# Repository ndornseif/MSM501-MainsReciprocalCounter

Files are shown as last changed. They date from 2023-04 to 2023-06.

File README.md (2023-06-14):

# MSM501-Mains Reciprocal Counter
Measures the frequency of mains power.  

## Overview
This device was built as an exercise in digital electronics.  
It uses a reciprocal frequency counter approach to measure the frequency of the mains voltage supplying it.   
Using two SN74LV8154N 32-bit counters, it counts pulses of the mains signal and the reference clock.  
The start and end of the measurement are synchronized to the input signal, using a D-Flip-Flop to open the main gate.  
This eliminates the influence of gate time accuracy on the measurement.  
The measurement result is then calculated as follows:  
$f_{measured} = \frac{n_{SignalCounter}}{n_{RefCounter}} \times f_{Ref}$   
The measured value is sent out over serial (J2).  
Find a graph explaining the signal flow [here](Charts/Signalflow.pdf).  

## Board overview
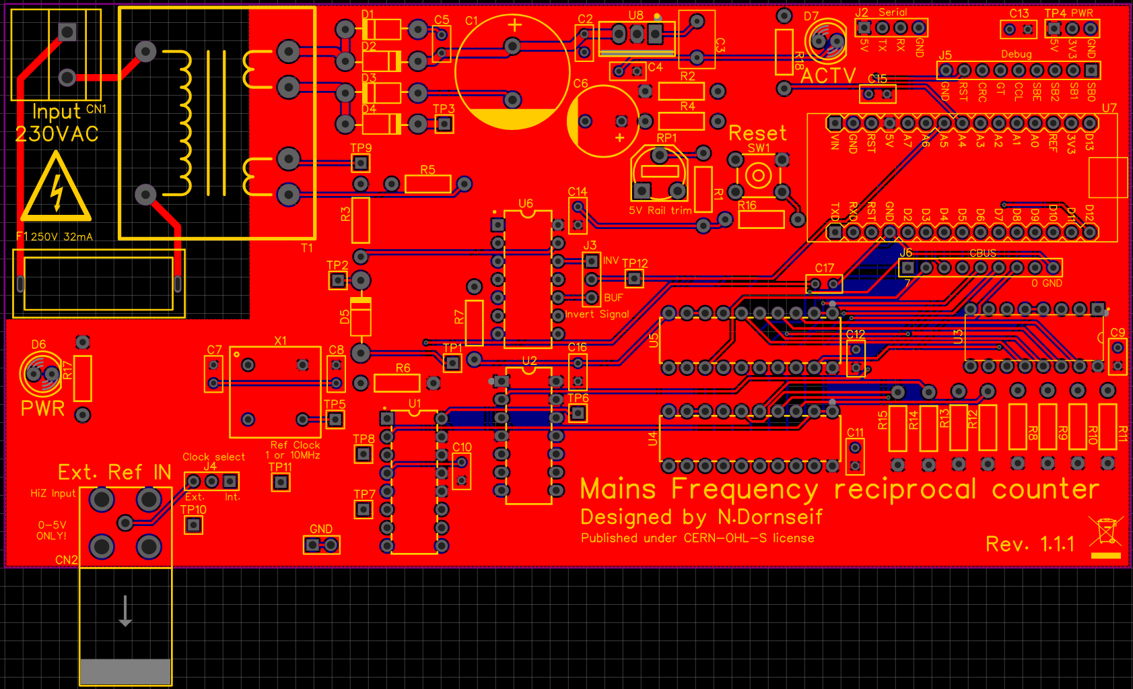
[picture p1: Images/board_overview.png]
Topside of the circuit board
  

## Connectors/Headers
- GND: Ground connection for scope ground clips.  
- TP4: DC voltage rails.
- J2: Serial interface. Connected to D0 and D1 of the Arduino. (5V max.)
- J5: Debug pins. (SBUS0, SBUS1, SBUS2, SBUSE, CounterClear, GateTime, CounterRegClock, Reset)
- J6: CBUS. Used to read out the counter values.
- CN1: Mains input. Fuse with a 5x20mm 32mA glass fuse in F1.
- CN2: External reference input. BNC. 0–5V square wave only. HiZ input.

## Jumpers
- JMP1 (J3): Selects if the measured signal is inverted. This should not affect the measured value. The recommended setting is INV.
- JMP2 (J4): Selects an external or internal reference clock. Check TP11 for the selected signal.

## Test points
- TP1:  Offset voltage to compensate for the clipping diode drop. (~ 500mV DC)
- TP2:  Divided and clipped transformer output voltage. (~ 4V<sub>p</sub> half-wave rectified sine)
- TP3:  Unregulated rectified and smoothed transformer voltage. (> 17V DC)
- TP4:  DC supply rails. (+5V and +3.3V DC)
- TP5:  Reference oscillator signal. (1 MHz or 10 MHz 0–5V square wave)
- TP6:  Gate-Enable signal from Flip-Flop. High if the main gate is open and the measurement is running.
- TP7:  Input to the signal counter.
- TP8:  Input to the reference counter.
- TP9:  Transformer output voltage to measurement circuit. (> 12V AC)
- TP10: External reference clock input.
- TP11: Reference input to the main gate. Should show the same signal as TP10 or TP5 depending on JMP2 (clock select).
- TP12: Signal input to the main gate. (0-5V square wave with the same frequency as the mains)

## Trimmers
- RP1:  Use this pot to adjust the voltage of the 5V rail.  

## Firmware 
Find the firmware for this project in this [repository](https://github.com/ndornseif/MSM501-Firmware).  
You can just upload it using the official Arduino IDE onto the Arduino Nano (U7).  
Remove the Arduino from the board when uploading firmware.  
Measurement results are in uHz and sent out over serial.  
They are sent as ASCII and separated by LF and CR.   
Default parameters: 115200 baud, 8 data, 1 stop, no parity  

## Example data
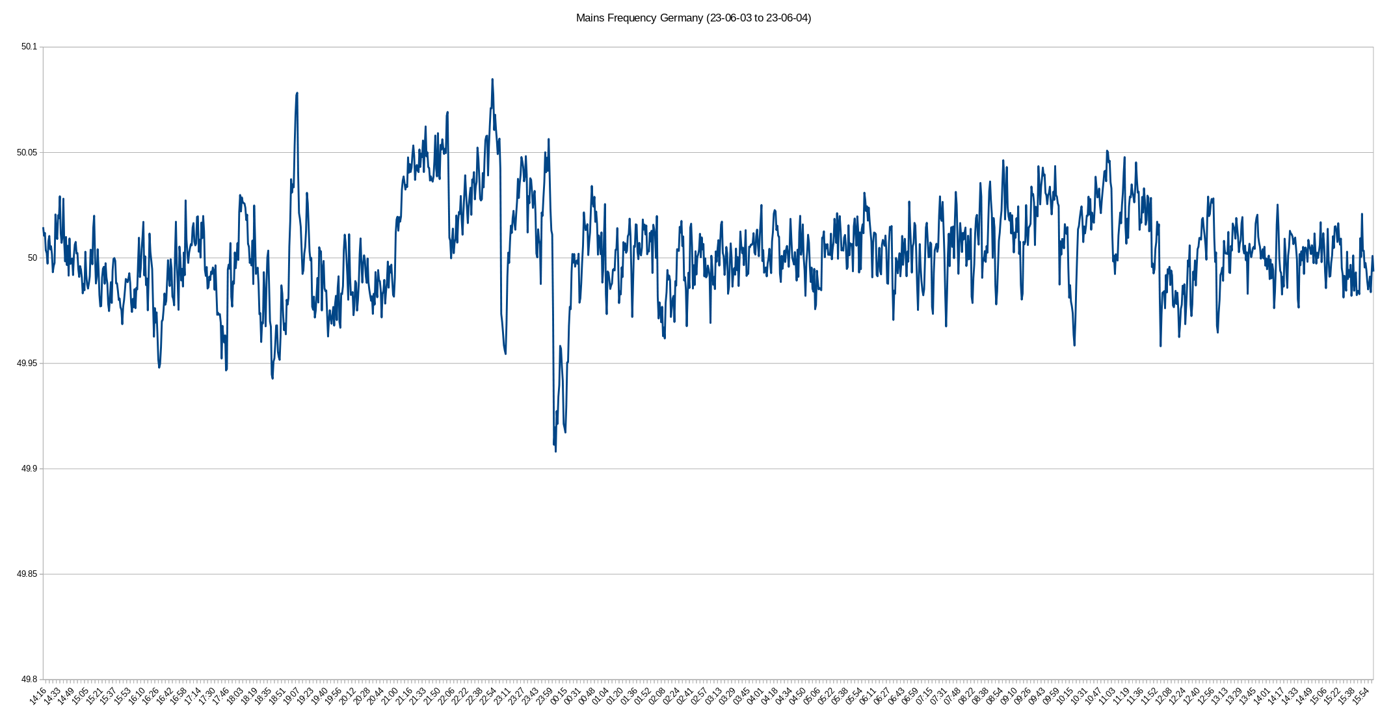
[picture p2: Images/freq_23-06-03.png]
Mains Frequency in Germany


## Considerations
Trying to power the Arduino through its USB header while the device is connected to the mains is not recommended.  
Use J2 (serial) for communication while mains is applied.  

## Other
Published under CERN-OHL-S license.

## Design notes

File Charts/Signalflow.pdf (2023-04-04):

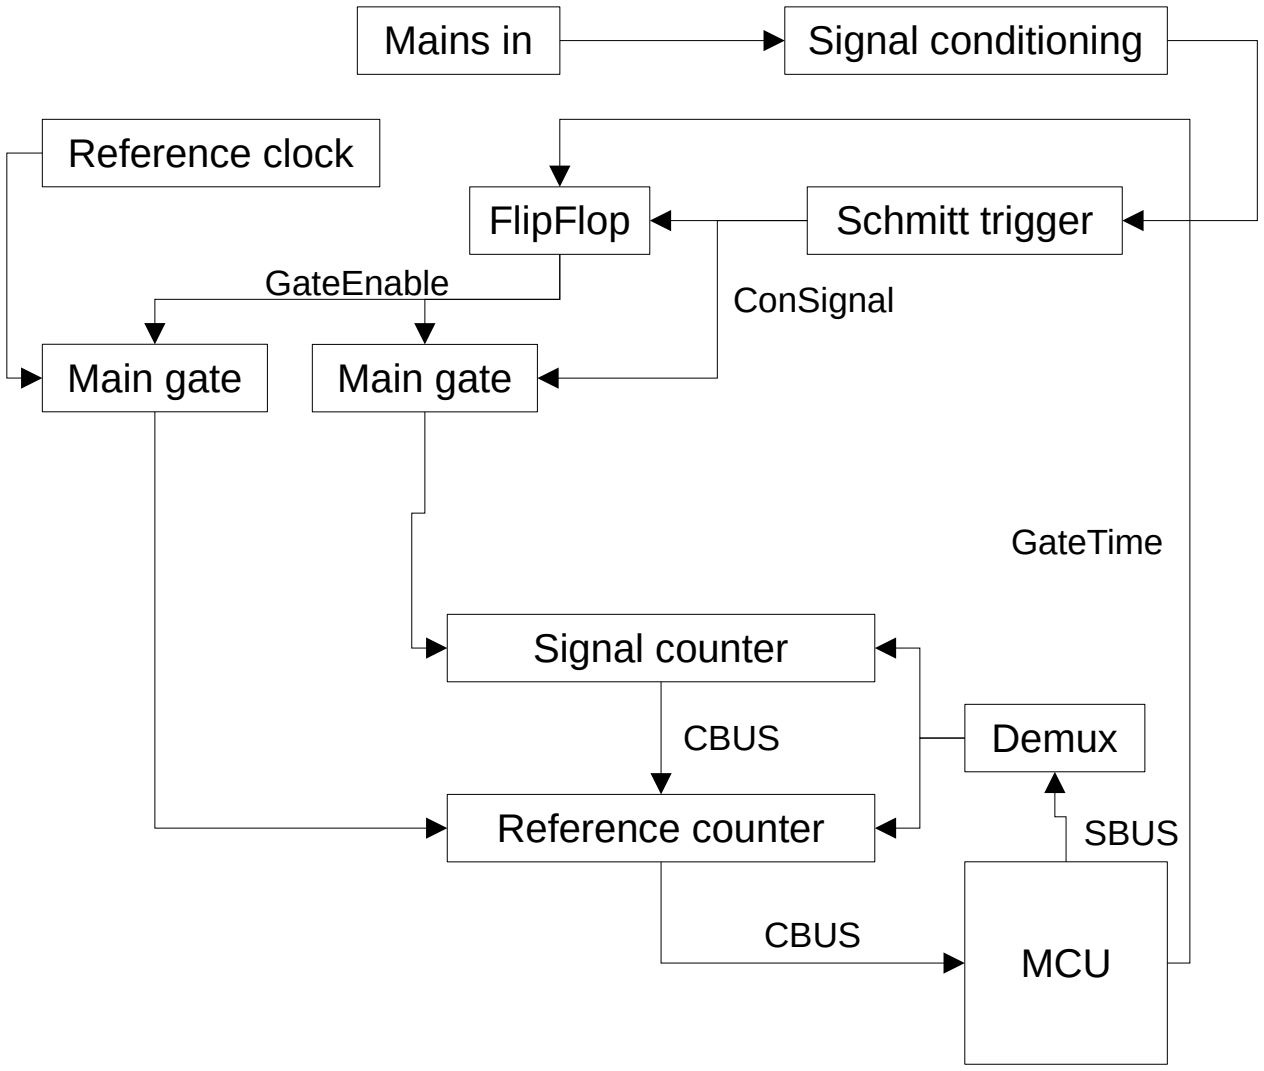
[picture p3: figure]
Reference counter; Signal counter; Demux; MCU; SBUS; Main gate; FlipFlop; Signal conditioning; Schmitt trigger; Mains in; Reference clock; GateEnable; ConSignal; CBUS; GateTime

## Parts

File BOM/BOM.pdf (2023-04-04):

MSM501-BOM

Page 1

Name | Designator | Footprint | Quantity
R 330k | R5 | R_AXIAL-0.4 | 1
R 1.2k | R7 | R_AXIAL-0.4 | 1
R 100k | R8,R9,R10,R11,R12,R13,R14,R15,R16 | R_AXIAL-0.4 | 9
R 520 | R1 | R_AXIAL-0.4 | 1
R 240 | R2 | R_AXIAL-0.4 | 1
R 1M | R3 | R_AXIAL-0.4 | 1
R 1k | R4 | R_AXIAL-0.4 | 1
R 10k | R6 | R_AXIAL-0.4 | 1
R 470 | R17,R18 | R_AXIAL-0.4 | 2
Pot 1k | RP1 | RM065-V1 | 1
C 0.1u | C2,C4,C5,C7,C8,C9,C10,C11,C12,C13,C14,C15,C16,C17 RAD-0.1 | 14
C 1000u | C1 | CAP-D16.0XF7.5 | 1
C 1u | C3 | RAD-0.2 | 1
C 100u | C6 | CAP-D10.0×F5.0 | 1
D 1N4007 | D1,D2,D3,D4,D5 | 1N4007 | 5
5mm LED | D6, D7 | LED5MM | 2
LM317 | U8 | TO-220-3_L10.0-W4.5-P2.54-L | 1
74AC11008N | U1 | DIP-16_L19.7-W6.6-P2.54-LS7.6-BL | 1
SN74HC74N | U2 | DIP-14_L19.3-W6.4-P2.54-LS7.6-BL | 1
SN74HCT138NG4 | U3 | DIP-16_L19.3-W6.4-P2.54-LS7.9-BL | 1
SN74LV8154 | U5,U4 | DIP-20_L25.4-W6.4-P2.54-LS7.6-BL | 2
SN74HC14 | U6 | DIP-14_L19.2-W6.6-P2.54-LS10.9-BL 1
Arduino nano | U7 | | 1
Pin Header 1X3 | J3,J4,TP4 | HDR-M-2.54_1X3 | 3
Pin Header 1X9 | J5,J6 | HDR-M-2.54_1X9 | 2
Pin Header 1X1 | TP1,TP2,TP6,TP9,TP3,TP5,TP7,TP8,TP10,TP11,TP12 | HDR-M-2.54_1X1 | 11
Pin Header 1X4 | J2 | HDR-M-2.54_1X4 | 1
Screw Terminal | CN1 | CONN-TH_XY636-6.35-2P | 1
TH BNC Connector | CN2 | BNC-TH_BNC-3G-J-PCB | 1
Push Button | SW1 | KEY-TH_4P-L6.0-W6.0-P4.50-LS7.5 | 1
Fuse holder 5X20MM | F1 | 5X20-BLX-A | 1
ECS-2100AX | X1 | ECS-2100X | 1
12V Transformer | T1 | VB_2,3/2/12 | 1

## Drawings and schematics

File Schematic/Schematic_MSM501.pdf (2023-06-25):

Rectifier | Voltage Regulator

## Decoupling Capacitors

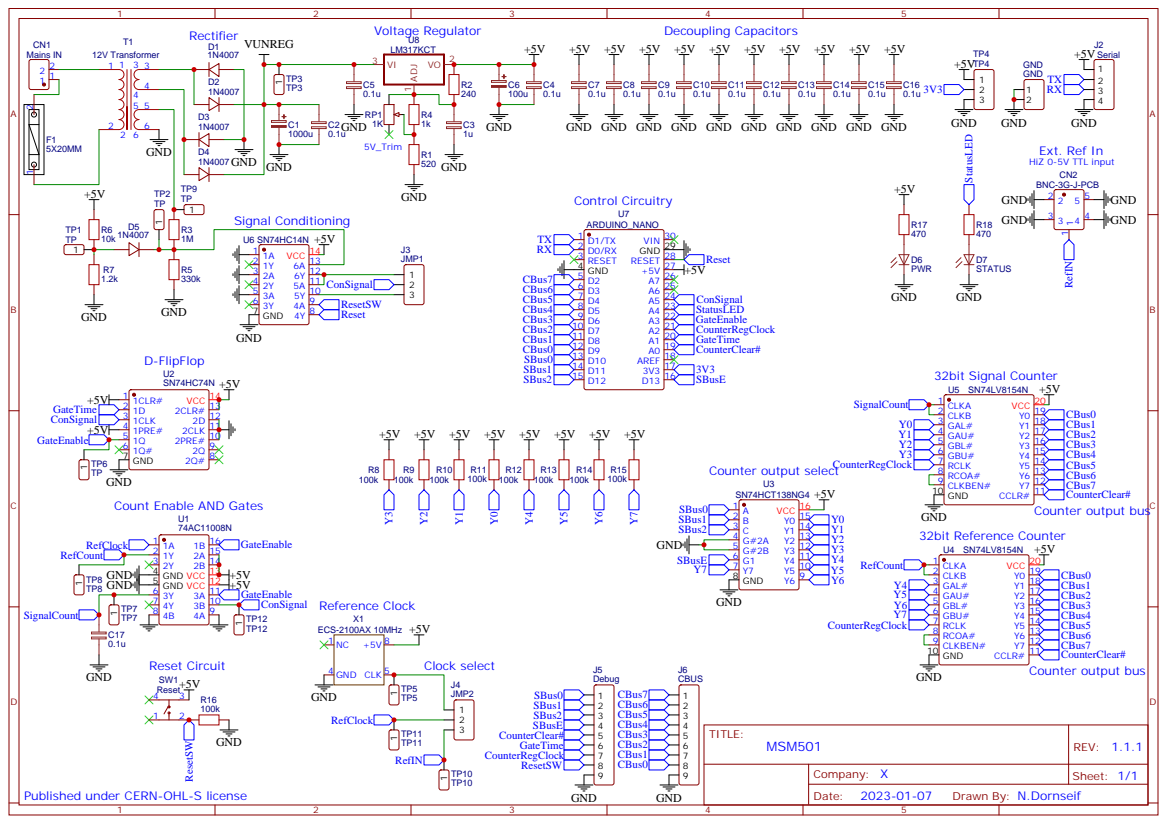
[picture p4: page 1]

GND GND GND

Published under CERN-OHL-S license

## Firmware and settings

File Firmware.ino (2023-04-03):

//Make sure StartPin has a higher pin number that EndPin.
#define CBUSStartPin 9 //First bit of the counter outputs. Should be connected to Y0.
//The next lower seven pins are the remainig CBUS pins. E.g. if CBUSStartPin is 9, connect Y0 to pin 9 and Y7 to pin 2

#define CounterClear A0 //Pin connected to CCLR# on both counters.
#define CounterRegClock A2 //Pin connected to RCLK on both counters.
#define GateTime A1 //Pin used to open the main gate and pass the signal and reference to the counters

//The SBUS is used to select which counter, as well as what byte of said counter will be read.
//SBUS2 selects the counter to read. 0=SignalCounter; 1=ReferenceCounter
//SBUS0 and SBUS1 are used to select one of the four bytes stored in each counter.
//0=CounterA lower byte, 1=CounterA upper byte, 2=CounterB lower byte, 3=CounterB upper byte.
//Pulling SBUSE low puts the outputs of both counters in HiZ mode. Leaves the CBUS floating. Pull high to read.
#define SBUS0 10
#define SBUS1 11
#define SBUS2 12
#define SBUSE 13

#define ReadGateStatus A3 //The pin connected to the gateEnable signal out of the flipflop. Used to sense if main gate is open.

#define StatusLED A4 //Red LED to indicate whatever. Connected to the positive terminal of the status LED.

#define ConditionedSignal A5 //The pin connected to the conditioned input signal. Used for general debugging.

//The frequency of the reference clock in uHz.
const float refClockFrequency = 1000000000000;

//The time a single measurment is perfomed by default in ms.
const unsigned long defaultGateTime = 60000;

//Resets Reference and Signal Counters.
void resetCounters(){
  digitalWrite(CounterClear,LOW);
  digitalWrite(CounterClear,HIGH);
}
//Latches the Reference and Signal Counter states in their internal registers.
void latchCounters(){
  digitalWrite(CounterRegClock,HIGH);
  digitalWrite(CounterRegClock,LOW);
}

byte readCBUS(){
  byte returnvalue = 0;
  for(byte i = 0; i < 8; i++){
    bitWrite(returnvalue,i,digitalRead(CBUSStartPin-i));
  }
  return returnvalue;
}

//Read counter in. counterIndex=0 -> Signal Counter; counterIndex=1 -> ReferenceCounter
unsigned long readCounter(bool counterIndex){
  unsigned long returnvalue = 0;
  byte SBUSState = 0b1011; //Set bit for SBUS enable high and byte counter (two LSBs) to three.
  bitWrite(SBUSState, 2, counterIndex);//Select the counter ro read from.
  for(byte i = 0; i < 4;i++){ //Extract all four bytes of the counter one by one
    setSBUS(SBUSState-i);
    returnvalue = returnvalue << 8;
    returnvalue += readCBUS();
  }
  return returnvalue;
}

//Sets the SBUS up for a read using the four least significant bits of index for SBUS0,SBUS1,SBUS2,SBUSE.
void setSBUS(byte index){
  digitalWrite(SBUS0, bitRead(index, 0));
  digitalWrite(SBUS1, bitRead(index, 1));
  digitalWrite(SBUS2, bitRead(index, 2));
  digitalWrite(SBUSE, bitRead(index, 3));
}

//Measures the Frequency coming in averaged over gateTime (in ms) returns value in uHz.
unsigned long performMeasurement(unsigned long gateTime){
  resetCounters();
  digitalWrite(LED_BUILTIN, HIGH);
  delay(500);
  digitalWrite(LED_BUILTIN, LOW);
  digitalWrite(GateTime,HIGH);
  delay(gateTime);
  digitalWrite(GateTime,LOW);
  delay(100);
  latchCounters();
  digitalWrite(LED_BUILTIN, HIGH);
  delay(500);
  digitalWrite(LED_BUILTIN, LOW);
  float signalCounterValue = readCounter(0);
  float referenceCounterValue = readCounter(1);
  //All Frequency values are given in uHz.
  unsigned long measuredFrequency = round((signalCounterValue * refClockFrequency) / referenceCounterValue);
  return measuredFrequency;
}
void setup() {
  Serial.begin(115200);
  //CBUS pins are numbered in decending order.
  for(byte i = 0; i < 8; i++){
    pinMode(CBUSStartPin-i, INPUT);
  }
  pinMode(ReadGateStatus,INPUT);
  pinMode(StatusLED,OUTPUT);
  pinMode(ConditionedSignal,INPUT);
  
  pinMode(LED_BUILTIN, OUTPUT);
  pinMode(CounterClear,OUTPUT);
  pinMode(CounterRegClock,OUTPUT);
  pinMode(GateTime,OUTPUT);
  pinMode(SBUS0,OUTPUT);
  pinMode(SBUS1,OUTPUT);
  pinMode(SBUS2,OUTPUT);
  pinMode(SBUSE,OUTPUT);

  digitalWrite(SBUSE,HIGH); //Disable CBUS.
  digitalWrite(CounterClear,HIGH); //Dont clear counter.
  digitalWrite(CounterRegClock,LOW); //Dont latch the counter state.
  digitalWrite(GateTime,LOW); //Leave main gate closed.
  analogWrite(StatusLED,0); //Status LED off.
  digitalWrite(LED_BUILTIN,LOW); //Arduino genral purpose LED off.

  resetCounters();
}

void loop() {
  delay(100);
  Serial.println(performMeasurement(defaultGateTime));
}

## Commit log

2023-04-03 new file: BOM.csv new file: Gerber/Drill_PTH_Through.DRL modified: README.md
    [BOM.csv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]
2023-04-04 File upload
    [BOM.csv, BOM.ods]
2023-04-04 BOM as PDF
    [BOM.ods]
2023-04-04 Cosmetic changes to Gerber and Schematic.
    [Drill_PTH_Through.DRL, Drill_PTH_Through_Via.DRL, Gerber_BoardOutlineLayer.GKO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]
2023-06-03 Added signal flow chart to README
2023-06-06 Changed copyright notice
    [Drill_PTH_Through.DRL, Drill_PTH_Through_Via.DRL, Gerber_BoardOutlineLayer.GKO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]
2023-06-18 Increased mains isolation distance
    [Drill_PTH_Through.DRL, Drill_PTH_Through_Via.DRL, Gerber_BoardOutlineLayer.GKO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]
2023-06-25 Tied unused inputs
    [Drill_PTH_Through.DRL, Drill_PTH_Through_Via.DRL, Gerber_BoardOutlineLayer.GKO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]
